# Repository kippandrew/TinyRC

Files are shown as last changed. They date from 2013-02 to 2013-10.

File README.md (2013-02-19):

TinyRC
==============

About
-----
The TinyRC is a open source hardware device for
converting servo signals from RC receivers (such as the Spektrum
AR6210) into a TTL serial stream that can be read by a microcontroller
such as an Arduino. 

The TinyRC works by timing the pulses received on up to
6 channels, and using an ATTiny84 microcontroller to convert those
pulses into a serial packet stream.

Hardware
--------
The TinyRC uses an ATTiny84 microcontroller from
Atmel. The board features and ISCP programming header, decoupling caps
and power indicator LED.

The board accepts a +5V source, and can provide power to the receiver. 

Schematic

Board

### Components ###

<table>
    <tr>
        <th>Part</th>
        <th>Description</th>
        <th>Part Number</th>
    </tr>
    <tr>
        <td>IC1</td>
        <td>Atmel ATTINY84A-SSU 14-SOIC SMD</td>
        <td>DigiKey P/N: <a href="http://www.digikey.com/product-detail/en/ATTINY84A-SSU/ATTINY84A-SSU-ND/3046522">ATTINY84A-SSU-ND</a></td>
    </tr>
    <tr>
        <td>C1</td>
        <td>Capcaitor 0.1uF</td>
        <td>DigiKey P/N: <a href="http://www.digikey.com/product-detail/en/C315C104M5U5TA/399-4151-ND/817927">399-4151-ND</a></td>
    </tr>
    <tr>
        <td>C2,C3</td>
        <td>CAP CER 22PF 50V 5% SMD 0805</td>
        <td>DigiKey P/N: <a href="http://www.digikey.com/product-detail/en/CC0805JRNPO9BN220/311-1103-1-ND/303013">311-1103-1-ND</a></td>
    </tr>
    <tr>
        <td>Y1</td>
        <td>CRYSTAL 20.0MHZ 50PF THRU</td>
        <td>DigiKey P/N: <a href="http://www.digikey.com/product-detail/en/ATS20B/CTX1108-ND/2640039">CTX1108-ND</a></td>
    </tr>
    <tr>
        <td>D1</td>
        <td>Diode SOD-323 SMD</td>
        <td>DigiKey P/N: <a href="http://www.digikey.com/product-detail/en/BAS316,115/568-5003-1-ND/2209919">568-5003-1-ND</a></td>
    </tr>
    <tr>
        <td>R1</td>
        <td>RES 330 OHM 5% 0805</td>
        <td>DigiKey P/N: <a href="http://www.digikey.com/product-detail/en/ERJ-P06J331V/P330ADCT-ND/525496">P330ADCT-ND</a></td>
    </tr>
    <tr>
        <td>LED1</td>
        <td>LED Red 1206 SMD</td>
        <td>DigiKey P/N: <a href="http://www.digikey.com/product-detail/en/LTST-C150CKT/160-1167-1-ND/269239">160-1167-1-ND</a></td>
    </tr>
    <tr>
        <td>JP1</td>
        <td>0.1" pitch Header 2x5</td>
        <td>DigiKey P/N: <a href="http://www.digikey.com/product-detail/en/67997-410HLF/609-3243-ND/1878475">609-3243-ND</a></td>
    </tr>
    <tr>
        <td>JP2</td>
        <td>0.1" pitch Header 2x3</td>
        <td>DigiKey P/N: <a href="http://www.digikey.com/product-detail/en/77313-422R06LF/609-4517-ND/2665635">609-4517-ND</a></td>
    </tr>
    <tr>
        <td>JP3</td>
        <td>0.1" pitch Header 1x3</td>
        <td>DigiKey P/N: <a href="http://www.digikey.com/product-detail/en/68000-103HLF/609-3461-ND/2023309">609-3461-ND</a></Otd>
    </tr>
</table>

Software
--------

The TinyRC runs and ATTINY Arduino core
(instructions on how to use the ATTINY Arduino core can be found
[here](http://hlt.media.mit.edu/?p=1695)). To program the board you
will need and AVR ISP programmer such as the [Pocket AVR
Programmer](https://www.sparkfun.com/products/9825) from SparkFun. It
is also possible to using a standard Arduino as an ISP programmer.

When programming the TinyRC for the first time, be
sure to burn the bootloader, and set the fuse bits for 8Mhz clock. The
default for the ATTiny84 is 1Mhz.

Instructions
------------

By default the TinyRC will output a 17 byte serial
packet every 100ms. The first 4 bytes are a header used to identify
the start of the packet. The packet header is 4 bytes with a value 0xFF.
Following the packet header is 1 byte of receiver status. This is currently
unused. Each channel follows the packet header encoded in two bytes.

Example Packet:

    --------------------------------------------------------------------------------------------------------------------------------------------
    | header (4 bytes)       | Status (1 byte) | CH1 (2 bytes) | CH2 (2 bytes) | CH3 (2 bytes) | CH4 (2 bytes) | CH5 (2 bytes) | CH6 (2 bytes) |
    --------------------------------------------------------------------------------------------------------------------------------------------
    | 0xFF, 0xFF, 0xFF, 0xFF | 0x00            | 0x00, 0x01    | 0x02, 0x03    | 0x04, 0x05    | 0x06, 0x07    | 0x06, 0x07    | 0x08, 0x0A    |
    --------------------------------------------------------------------------------------------------------------------------------------------

Example reading the packet from Arduino (Mega):

    uint8_t packetHeader[4] = {
      0xFF, 0xFF, 0xFF, 0xFF};

    void setup() {
      // initialize serial
      Serial.begin(115200); 
      Serial1.begin(9600);
    }

    boolean readPacketHeader(uint8_t *header, size_t headerLength, uint32_t timeout) {
      byte index = 0;
      byte b = 0;
      uint32_t startTime = millis();
      while (millis() - startTime < timeout) {
        if (index >= headerLength) {
          return true;
        }
        if (Serial1.available() > 0) {
          b = Serial1.read();
          if (b == header[index]) {
            index++;
          } 
          else {
            index = 0;
          }
        }
      }
      // timeout
      return false;
    }

    void loop() {
      static uint16_t channels[6];
      byte len;
      uint8_t buf[2];
      uint8_t status;

      if (readPacketHeader(packetHeader, 4, 10)) {
        status = Serial1.read();
        // for each channel
        for (int ch = 0; ch < 6; ch++) {
          // Read two bytes
          len = Serial1.readBytes((char*)buf, 2);
          if (len >= 2) {
            memcpy(&channels[ch], buf, sizeof(uint16_t));
          }
        }
      }
      
      for (int ch = 0; ch < 6; ch++) {
        Serial.print("ch ");
        Serial.print(ch + 1, DEC);
        Serial.print(" ");
        Serial.print(channels[ch]);
        Serial.print(" ");
      }
      
      Serial.println();

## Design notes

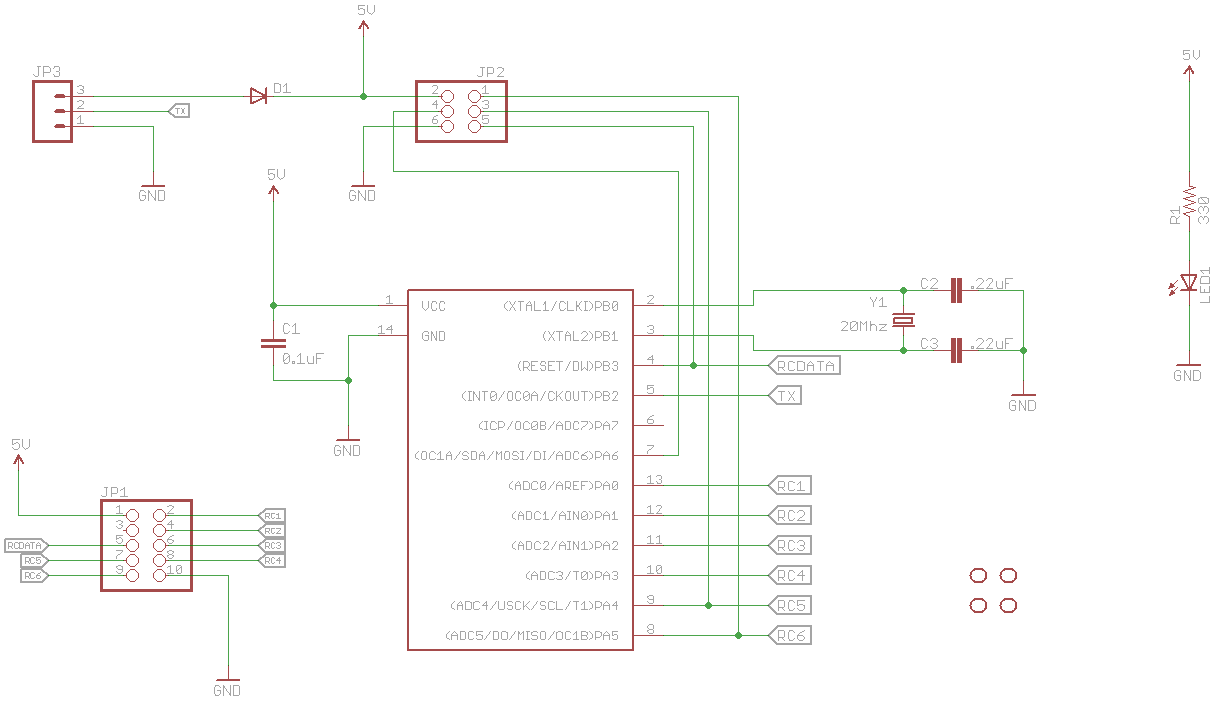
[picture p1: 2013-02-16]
tiny-rc-serial-schematic.png

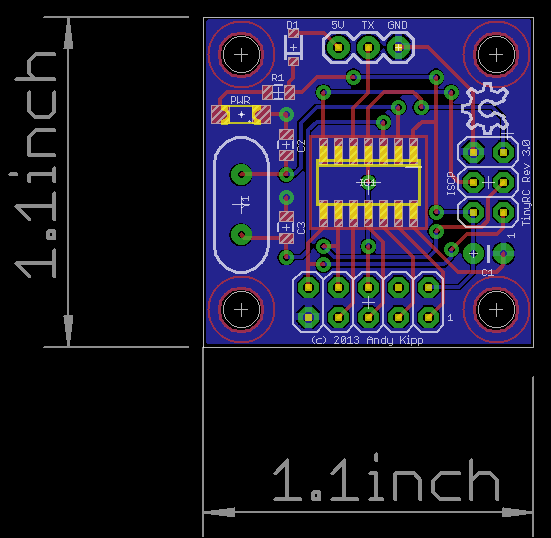
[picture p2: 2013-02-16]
tiny-rc-serial-board.png

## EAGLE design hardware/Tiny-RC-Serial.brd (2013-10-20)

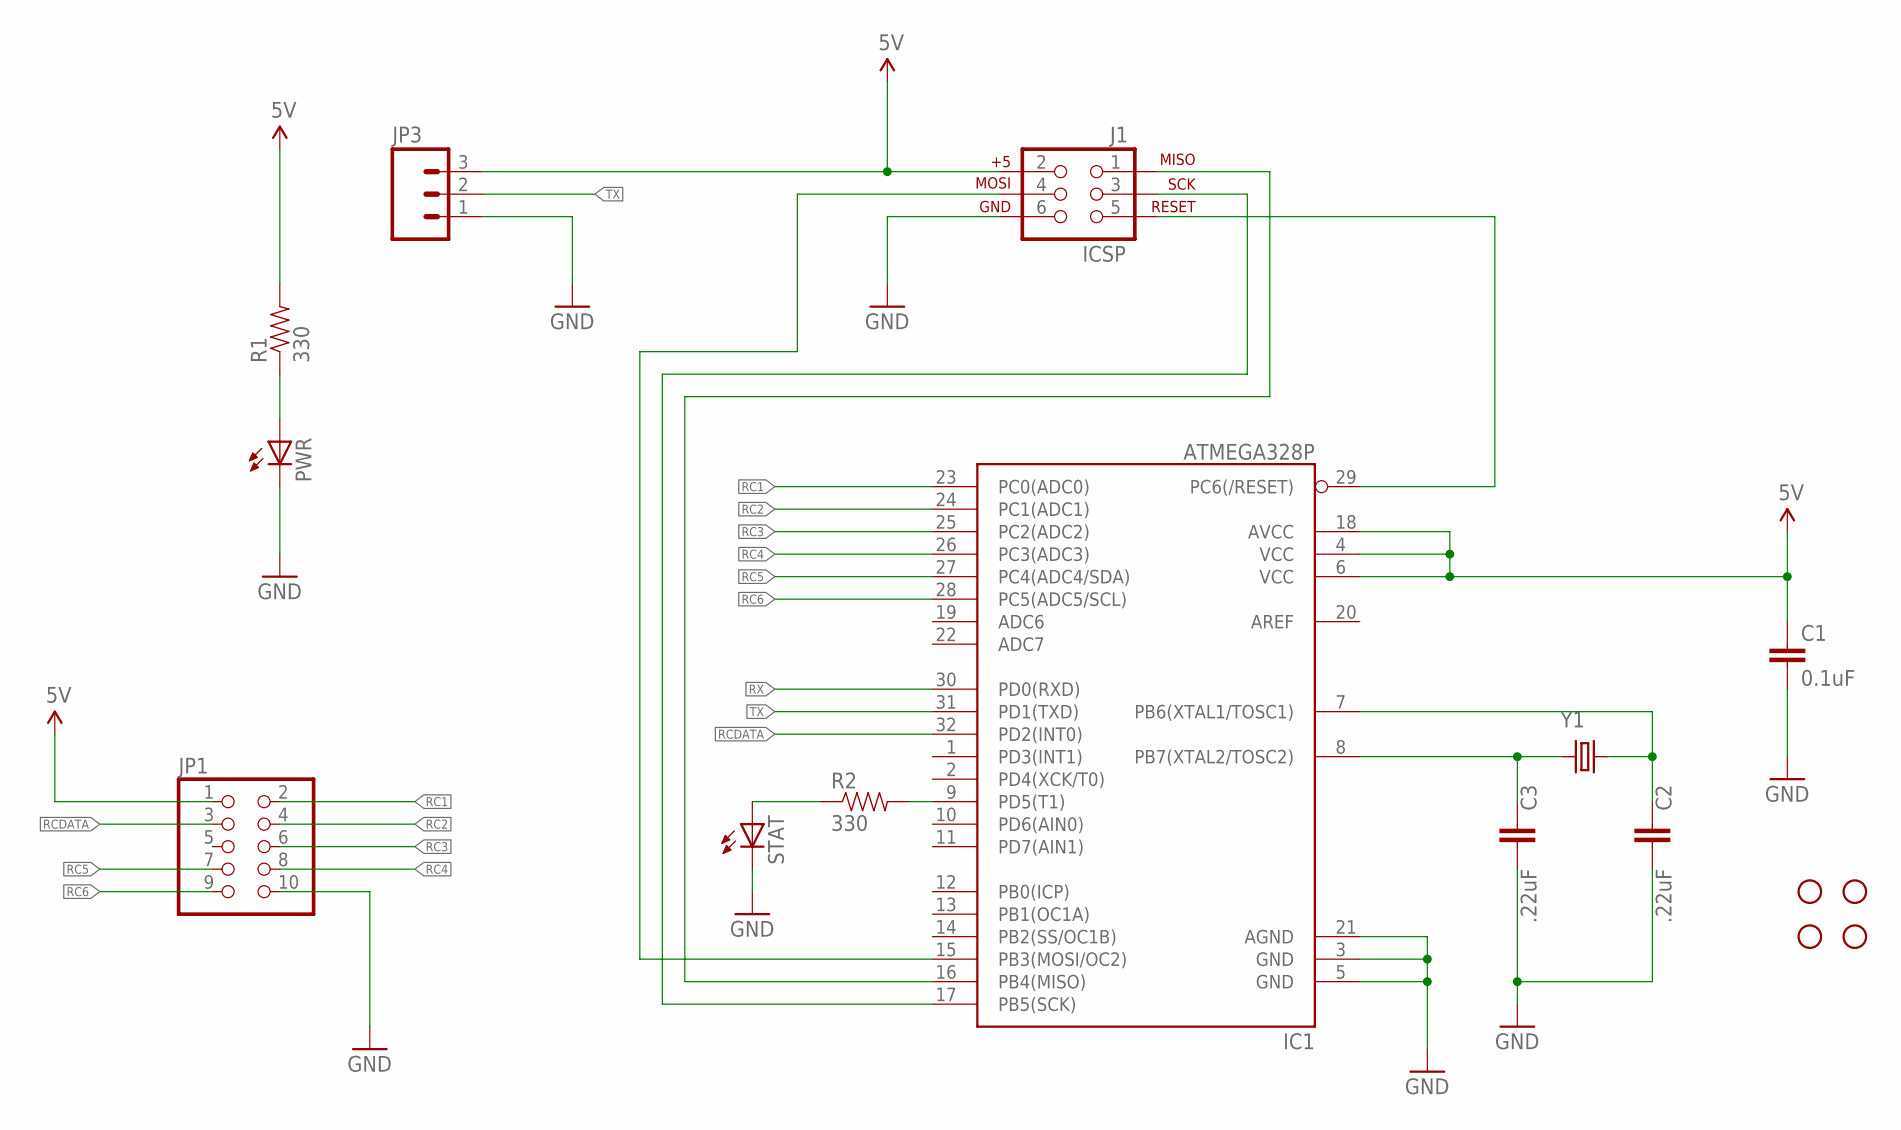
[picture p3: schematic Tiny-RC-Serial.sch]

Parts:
C1: 0.1uF; CAP-PTH-SMALL-KIT
C2, C3: .22uF; CAP-PTH-SMALL-KIT
IC1: ATMEGA328P; TQFP32-08
J1: ICSP; 2X3
JP1: PINHD-2X5; 2X05
JP3: M03PTH; 1X03
PWR: LED1206; LED-1206
R1, R2: 330; 1206
S1, S2, S3, S4: STAND-OFFTIGHT; STAND-OFF-TIGHT
STAT: LED1206; LED-1206
Y1: 20Mhz; HC49US

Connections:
5V: C1.1, IC1.4 (VCC), IC1.6 (VCC), IC1.18 (AVCC), J1.2, JP1.1, JP3.3, R1.2
GND: C1.2, C2.2, C3.2, IC1.3 (GND), IC1.5 (GND), IC1.21 (AGND), J1.6, JP1.10, JP3.1, PWR.C, STAT.C
MISO: IC1.16 (PB4(MISO)), J1.1
MOSI: IC1.15 (PB3(MOSI/OC2)), J1.4
unnamed: IC1.9 (PD5(T1)), R2.2
unnamed: PWR.A, R1.1
unnamed: C2.1, IC1.7 (PB6(XTAL1/TOSC1)), Y1.2
unnamed: C3.1, IC1.8 (PB7(XTAL2/TOSC2)), Y1.1
unnamed: R2.1, STAT.A
RC1: IC1.23 (PC0(ADC0)), JP1.2
RC2: IC1.24 (PC1(ADC1)), JP1.4
RC3: IC1.25 (PC2(ADC2)), JP1.6
RC4: IC1.26 (PC3(ADC3)), JP1.8
RC5: IC1.27 (PC4(ADC4/SDA)), JP1.7
RC6: IC1.28 (PC5(ADC5/SCL)), JP1.9
RCDATA: IC1.32 (PD2(INT0)), JP1.3
RESET: IC1.29 (PC6(/RESET)), J1.5
RX: IC1.30 (PD0(RXD))
SCK: IC1.17 (PB5(SCK)), J1.3
TX: IC1.31 (PD1(TXD)), JP3.2

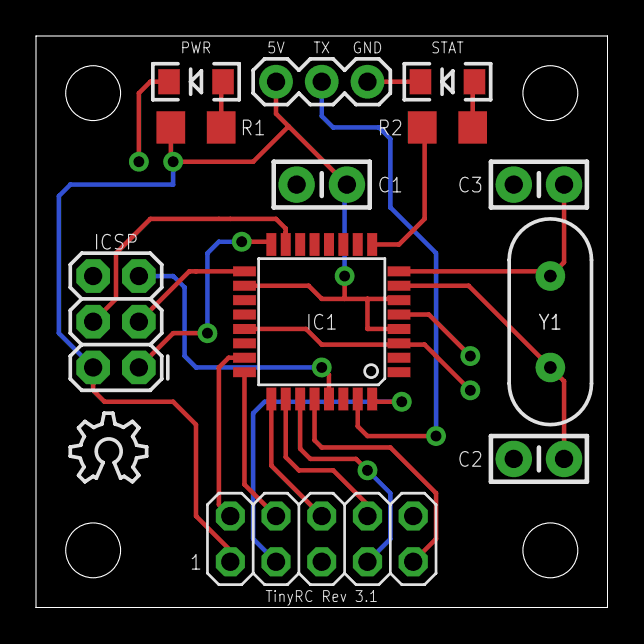
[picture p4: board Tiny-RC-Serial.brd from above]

Board: 2 copper layers, 31.8 x 31.8 mm, 17 parts (0 on the bottom side), 19 nets.

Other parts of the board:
U$5: OSHW_8X150_NOTEXT

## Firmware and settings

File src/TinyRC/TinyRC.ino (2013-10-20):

//
// Copyright (C) 2012-2013 Andy Kipp <kipp.andrew@gmail.com> 
//
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
// Reference: ATMEL ATMEGA328
//
//                           +-\/-+
//             RESET  PC6   1|    |28  PC5  (A 5)
//         (D 0) RX   PD0   2|    |27  PC4  (A 4)
//         (D 1) TX   PD1   3|    |26  PC3  (A 3)
//             (D 2)  PD2   4|    |25  PC2  (A 2)
//             (D 3)  PD3   5|    |24  PC1  (A 1)
//             (D 4)  PD4   6|    |23  PC0  (A 0)
//                    VCC   7|    |22  GND
//                    GND   8|    |21  AREF
//             XTAL1  PB6   9|    |20  AVCC (A 0)
//             XTAL2  PB7  10|    |19  PB5  (D 13)
//             (D 5)  PD5  11|    |18  PB4  (D 12)
//             (D 6)  PD6  12|    |17  PB3  (D 11)
//             (D 7)  PD7  13|    |16  PB2  (D 10)
//             (D 8)  PD0  14|    |15  PB1  (D 9)
//                           +----+

#define RECEIVER_CH1 0
#define RECEIVER_CH2 1
#define RECEIVER_CH3 2
#define RECEIVER_CH4 3
#define RECEIVER_CH5 4
#define RECEIVER_CH6 5

#define RECEIVER_CH1_IN_PIN 0  // PC0 / A0 / PCINT8
#define RECEIVER_CH2_IN_PIN 1  // PC1 / A1 / PCINT9
#define RECEIVER_CH3_IN_PIN 2  // PC2 / A2 / PCINT10
#define RECEIVER_CH4_IN_PIN 3  // PC3 / A3 / PCINT11
#define RECEIVER_CH5_IN_PIN 4  // PC4 / A4 / PCINT12
#define RECEIVER_CH6_IN_PIN 5  // PC5 / A5 / PCINT13

#define RECEIVER_CH1_FLAG 1
#define RECEIVER_CH2_FLAG 2
#define RECEIVER_CH3_FLAG 3
#define RECEIVER_CH4_FLAG 4
#define RECEIVER_CH5_FLAG 5
#define RECEIVER_CH6_FLAG 6

#define NUMBER_RECEIVER_CHANNELS 6

#define RECEIVER_STATUS_WATCHDOG   1

#define STARTUP_TIMER 500
#define OUTPUT_TIMER 100
#define WATCHDOG_TIMER 500

//#define DEBUG_SERIAL_OUTPUT

// Serial packet header
const uint8_t serialPacketHeader[4] = {0xFF, 0xFF, 0xFF, 0xFF};

// define receiver_interrupt struct
struct receiver_interrupt_t {
    uint8_t  pin;
    uint8_t  channel;
    uint8_t  bitMask;
};

// array of receiver_interrupt structs for each channel
volatile receiver_interrupt_t receiver_interrupts[NUMBER_RECEIVER_CHANNELS];

// receiver channel update flag 
volatile uint8_t shared_receiver_update_flags;

// receiver elasped time for each receiver channel
volatile uint16_t shared_receiver_timer[NUMBER_RECEIVER_CHANNELS];

// receiver start time for each receiver channel
volatile uint32_t shared_receiver_timer_start[NUMBER_RECEIVER_CHANNELS];

// watchdog timer
volatile uint32_t watchdog_timer = 0;

// receiver status flags
volatile uint8_t receiver_status_flags = 0;

// Serial output timer
volatile uint32_t output_timer = 0;

// Serial interface
//SoftwareSerial SoftwareSerial(SERIAL_RX_PIN, SERIAL_TX_PIN); // RX, TX

/**
 * setup a receiver_interrupt for the given channel on the given pin
 */
void setupReceiverInterrupt(uint8_t pin, uint8_t channel) {

  volatile receiver_interrupt_t *inrpt;

  // Get interrupt
  inrpt = &receiver_interrupts[channel];

  // Get bit mask for pin
  uint8_t bitMask = digitalPinToBitMask(pin);

  // Set interrupt data
  inrpt->bitMask = bitMask;
  inrpt->pin = pin;
  inrpt->channel = channel;

  // Enable pin change interrupt
  //GIMSK |= (1<<PCIE);
  PCICR |= (1<<1);
  if ( (PCMSK1 & bitMask) == 0 )
  {
    PCMSK1 |= bitMask;
  }
}

/**
 * handle interrupt for the given pin and channel
 */
void handleReceiverInterrupt(uint8_t pin, uint8_t channel) {
  // if the pin is high, its a rising edge of the signal pulse, so lets record its value
  if(digitalRead(pin) == HIGH)
  {
    shared_receiver_timer_start[channel] = micros();
  }
  else
  {
    // else it must be a falling edge, so lets get the time and subtract the time of the rising edge
    // this gives use the time between the rising and falling edges i.e. the pulse duration.
    shared_receiver_timer[channel] = (uint16_t)(micros() - shared_receiver_timer_start[channel]);
    // set the channel flag to indicate that a new channel signal has been received
    uint8_t flag = channel + 1;
    shared_receiver_update_flags |= flag;
  }
}

/**
 * arduino setup
 */
void setup()
{
  // Open Serial communications and wait for port to open
  Serial.begin(9600);

  // setup receiver interrupts

  //setupReceiverInterrupt(analogInputToDigialPin(RECEIVER_CH1_IN_PIN), RECEIVER_CH1);
  setupReceiverInterrupt(analogInputToDigitalPin(RECEIVER_CH2_IN_PIN), RECEIVER_CH2);
  //setupReceiverInterrupt(RECEIVER_CH3_IN_PIN, RECEIVER_CH3);
  //setupReceiverInterrupt(RECEIVER_CH4_IN_PIN, RECEIVER_CH4);
  //setupReceiverInterrupt(RECEIVER_CH5_IN_PIN, RECEIVER_CH5);
  //setupReceiverInterrupt(RECEIVER_CH6_IN_PIN, RECEIVER_CH6);
  sei();

  delay(STARTUP_TIMER);
}

/**
 * arduino loop
 */
void loop()
{
  static uint8_t receiver_update_flags;
  static uint16_t receiver[NUMBER_RECEIVER_CHANNELS];
  uint8_t buf[sizeof(uint16_t)];

  // check shared update flags to see if any channels have a new signal
  if(shared_receiver_update_flags)
  {
    noInterrupts(); // turn interrupts off quickly while we take local copies of the shared variables

    // update watchdog timer
    watchdog_timer = millis();

    // take a local copy of which channels were updated in case we need to use this in the rest of loop
    receiver_update_flags = shared_receiver_update_flags;

    // check for updated channels
    if(receiver_update_flags & RECEIVER_CH1_FLAG)
    {
      receiver[RECEIVER_CH1] = shared_receiver_timer[RECEIVER_CH1];
    }
    if(receiver_update_flags & RECEIVER_CH2_FLAG)
    {
      receiver[RECEIVER_CH2] = shared_receiver_timer[RECEIVER_CH2];
    }
    if(receiver_update_flags & RECEIVER_CH3_FLAG)
    {
      receiver[RECEIVER_CH3] = shared_receiver_timer[RECEIVER_CH3];
    }
    if(receiver_update_flags & RECEIVER_CH4_FLAG)
    {
      receiver[RECEIVER_CH4] = shared_receiver_timer[RECEIVER_CH4];
    }
    if(receiver_update_flags & RECEIVER_CH5_FLAG)
    {
      receiver[RECEIVER_CH5] = shared_receiver_timer[RECEIVER_CH5];
    }
    if(receiver_update_flags & RECEIVER_CH6_FLAG)
    {
      receiver[RECEIVER_CH6] = shared_receiver_timer[RECEIVER_CH6];
    }

    // clear shared copy of updated flags as we have already taken the updates
    shared_receiver_update_flags = 0;

    interrupts(); // turn interrupts back on
  }

  // check watchdog timer
  if ((millis() - watchdog_timer) >= WATCHDOG_TIMER) {
    receiver_status_flags |= RECEIVER_STATUS_WATCHDOG;
  } else {
    receiver_status_flags &= ~RECEIVER_STATUS_WATCHDOG;
  }

#ifdef DEBUG_Serial.OUTPUT 

  Serial.write(0xFE);
  Serial.write(0x01);
  Serial.print(receiver_status_flags, HEX);
  Serial.print(" ");
  Serial.print(receiver[RECEIVER_CH1], DEC);
  Serial.print(" ");
  Serial.print(receiver[RECEIVER_CH2], DEC);
  Serial.print(" ");
  Serial.print(receiver[RECEIVER_CH3], DEC);
  Serial.print(" ");
  Serial.print(receiver[RECEIVER_CH4], DEC);
  Serial.print(" ");
  Serial.print(receiver[RECEIVER_CH5], DEC);
  Serial.print(" ");
  Serial.print(receiver[RECEIVER_CH6], DEC);
  delay(100);

#else

  // only write to the Serial.stream after OUTPUT_TIMER milliseconds
  if ((millis() - output_timer) >= OUTPUT_TIMER) {

    // update output timer
    output_timer = millis();

    // write packet header 
    Serial.write(serialPacketHeader, sizeof(serialPacketHeader));

    // write receiver output to serial
    memcpy(buf, &receiver[RECEIVER_CH1], sizeof(uint16_t));
    Serial.write(buf, sizeof(uint16_t));
    memcpy(buf, &receiver[RECEIVER_CH2], sizeof(uint16_t));
    Serial.write(buf, sizeof(uint16_t));
    memcpy(buf, &receiver[RECEIVER_CH3], sizeof(uint16_t));
    Serial.write(buf, sizeof(uint16_t));
    memcpy(buf, &receiver[RECEIVER_CH4], sizeof(uint16_t));
    Serial.write(buf, sizeof(uint16_t));
    memcpy(buf, &receiver[RECEIVER_CH5], sizeof(uint16_t));
    Serial.write(buf, sizeof(uint16_t));
    memcpy(buf, &receiver[RECEIVER_CH6], sizeof(uint16_t));
    Serial.write(buf, sizeof(uint16_t));

    // write receiver status flags 
    Serial.write(receiver_status_flags);

  }

#endif

}

/**
 * interrupt service routine for pin change interrupt (PORTA)
 */
ISR( PCINT1_vect )
{
  volatile static uint8_t prevPinState;

  uint8_t currentPinState = PORTC & PCMSK1;
  uint8_t bitMask = currentPinState ^ prevPinState;

  volatile receiver_interrupt_t *inrpt;

  inrpt = receiver_interrupts;
  for ( uint8_t i=0; i < NUMBER_RECEIVER_CHANNELS; i++ ) {
    if ((inrpt->bitMask & bitMask)){
      handleReceiverInterrupt(inrpt->pin, inrpt->channel);
      break;
    }
    ++inrpt;
  }

  prevPinState = currentPinState;
}

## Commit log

2012-12-30 intial commit
    [Tiny-RC-Serial.brd, Tiny-RC-Serial.sch]
2012-12-30 updated readme and sch and brd
    [Tiny-RC-Serial.brd, Tiny-RC-Serial.sch]
2013-02-16 updated to version 3.0
    [Tiny-RC-Serial.brd, Tiny-RC-Serial.sch]
2013-02-16 updated rinyrc board
    [Tiny-RC-Serial.brd]
2013-02-16 removed values
    [Tiny-RC-Serial.brd]
2013-02-19 updated tinyRC code with watchdog timer
2013-02-24 updated board to rev 3.0 - now using ATTiny2313
    [Tiny-RC-Serial.brd, Tiny-RC-Serial.sch]
2013-10-20 Update hardware to 3.1
    [Tiny-RC-Serial.brd, Tiny-RC-Serial.sch]

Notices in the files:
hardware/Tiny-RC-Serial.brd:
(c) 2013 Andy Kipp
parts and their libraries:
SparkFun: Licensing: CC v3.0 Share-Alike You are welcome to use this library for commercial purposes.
